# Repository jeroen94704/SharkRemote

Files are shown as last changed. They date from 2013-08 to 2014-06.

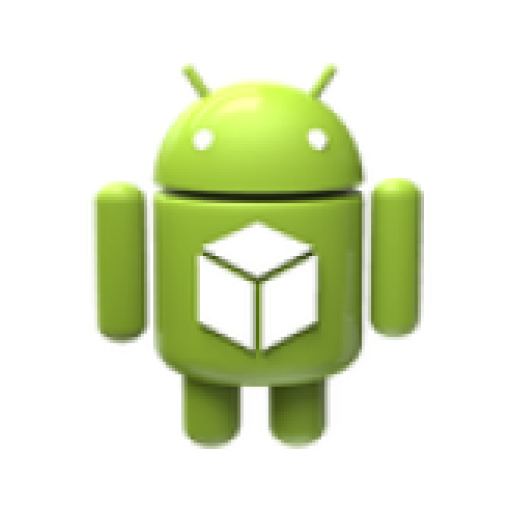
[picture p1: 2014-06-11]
AndroidApp/BruceControl/src/main/ic_launcher-web.png

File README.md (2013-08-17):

SharkRemote
===========

The goal of this project is to convert an AirSwimmer (http://www.airswimmers.com) helium balloon fish into to be controllable over a network. This is done by replacing the analog wireless control module with a n RFM12B wireless module controlled by an Atmega328 microcontroller. A base station in the form of a Nanode networked Arduino clone acts as a gateway between the RFM12B connection and the network. It provides a REST-like interface which can be used to control the AirSwimmer. 

RF12_Server
-----------

Some stuff about the server, such as the wireless protocol being used

RF12_Client
-----------

Something about the client, such as the design

REST interface
--------------

Something about the REST interface etc.

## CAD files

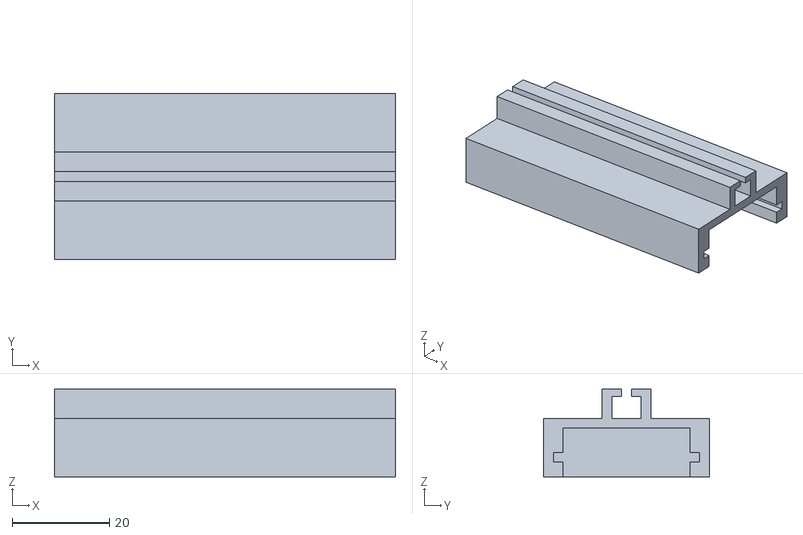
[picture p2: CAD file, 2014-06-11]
OpenScadFiles/PCB holder.stl
70.0 x 34.0 x 18.0

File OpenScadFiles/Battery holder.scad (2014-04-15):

union() {
	difference() {
		difference() {	
			translate([0,0,9])
				cube([35, 11, 6], center=true);
			translate([-1,0,8])
				cube([74, 7, 5], center=true);
		}
		translate([-1,0,10])
			cube([74, 2, 5], center=true);	
	}
	difference() {
		difference() {
			cube([35,23,12], center=true);
			translate([2, 0, -2])
			   cube([70,16,12], center=true);
		}
		translate([2, 0, 0])
		   cube([70,19,8], center=true);	
	}
}

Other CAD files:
OpenScadFiles/PCB holder.scad

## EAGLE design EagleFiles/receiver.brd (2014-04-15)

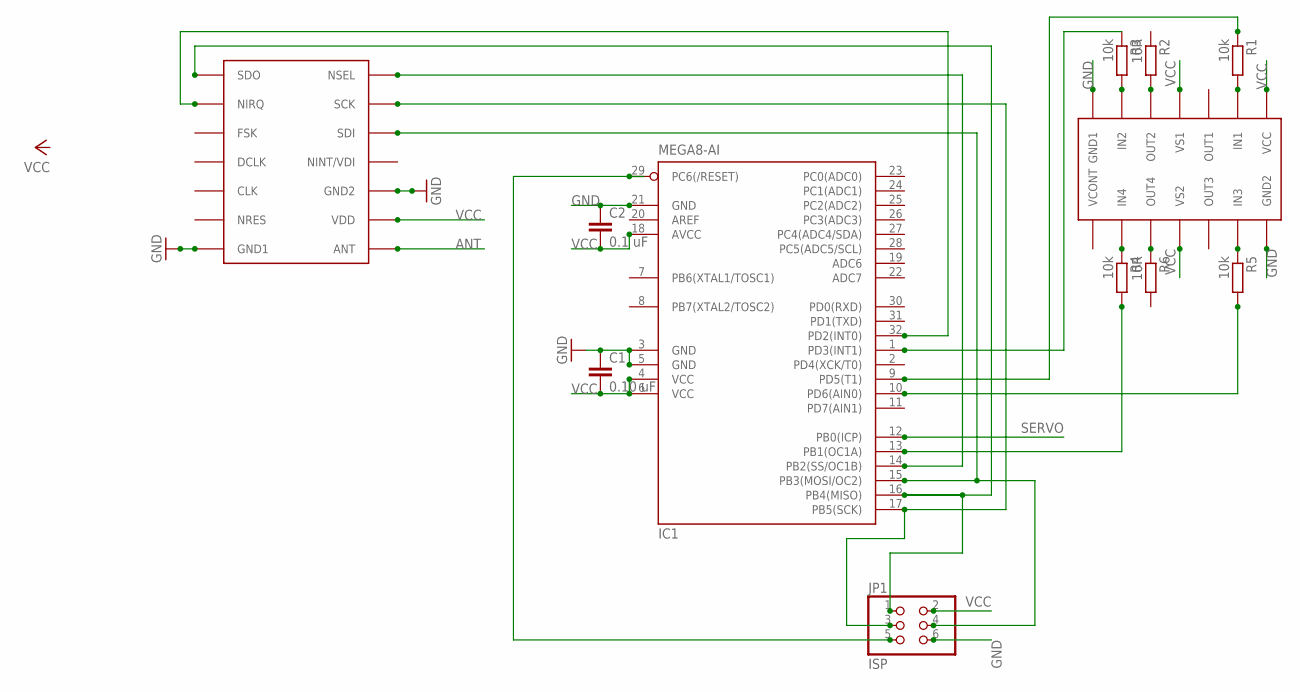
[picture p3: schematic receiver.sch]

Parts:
C1: 0.10 uF; C0805
C2: 0.1 uF; C0805
IC1: MEGA8-AI; TQFP32-08
JP1: ISP; 2X03
LB1836M: LB1836M; MFP-14
R1, R3, R4, R5: 10k; R2012
R2, R6: 10R; R2012
RFM12B: RFM12B

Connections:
ANT: RFM12B.ANT
GND: C1.1, C2.1, IC1.3 (GND), IC1.5 (GND), IC1.21 (GND), JP1.6, LB1836M.GN2 (GND2), LB1836M.GND1, RFM12B.GND1, RFM12B.GND2
unnamed: IC1.16 (PB4(MISO)), JP1.1, RFM12B.SDO
unnamed: IC1.15 (PB3(MOSI/OC2)), JP1.4, RFM12B.SDI
unnamed: IC1.17 (PB5(SCK)), JP1.3, RFM12B.SCK
unnamed: IC1.14 (PB2(SS/OC1B)), RFM12B.NSEL
unnamed: IC1.32 (PD2(INT0)), RFM12B.NIRQ
unnamed: LB1836M.IN1, R1.2
unnamed: IC1.9 (PD5(T1)), R1.1
unnamed: LB1836M.IN2, R3.2
unnamed: LB1836M.IN4, R4.1
unnamed: LB1836M.IN3, R5.1
unnamed: IC1.1 (PD3(INT1)), R3.1
unnamed: IC1.13 (PB1(OC1A)), R4.2
unnamed: IC1.10 (PD6(AIN0)), R5.2
unnamed: LB1836M.OUT2, R2.2
unnamed: LB1836M.OUT4, R6.1
unnamed: IC1.29 (PC6(/RESET)), JP1.5
SERVO: IC1.12 (PB0(ICP))
VCC: C1.2, C2.2, IC1.4 (VCC), IC1.6 (VCC), IC1.18 (AVCC), JP1.2, LB1836M.VCC, LB1836M.VS1, LB1836M.VS2, RFM12B.VDD

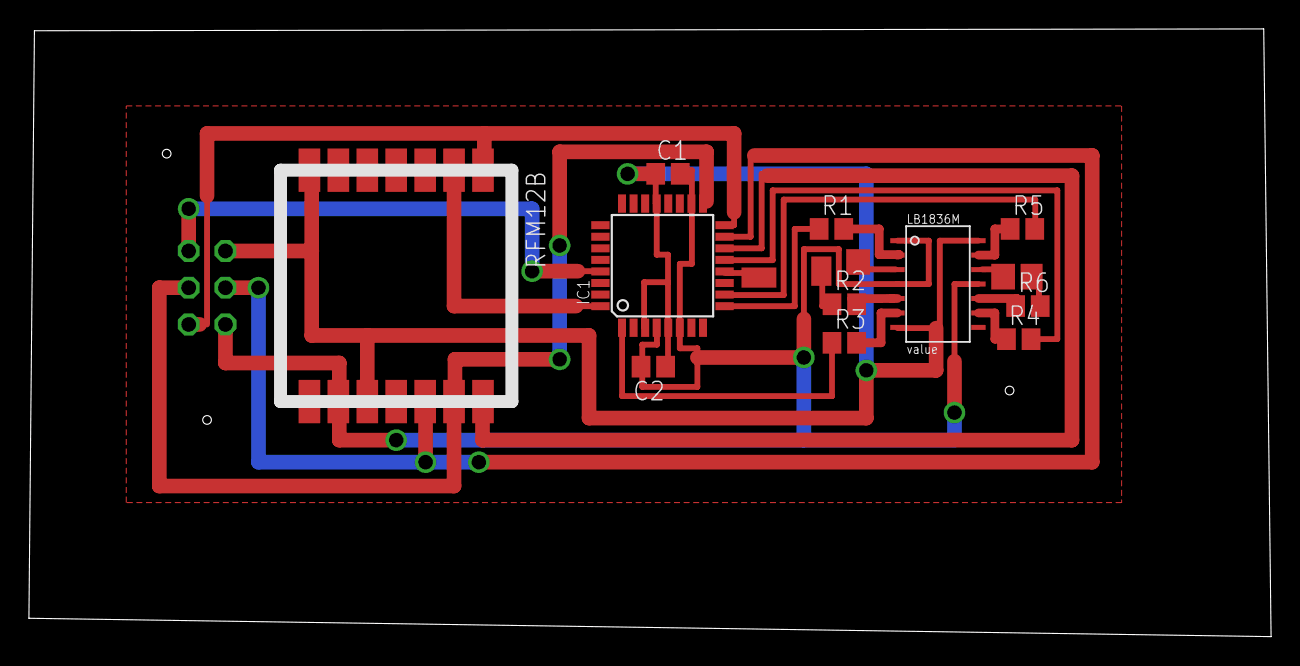
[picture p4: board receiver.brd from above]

Board: 2 copper layers, 85.9 x 42.0 mm, 12 parts (1 on the bottom side), 18 nets.

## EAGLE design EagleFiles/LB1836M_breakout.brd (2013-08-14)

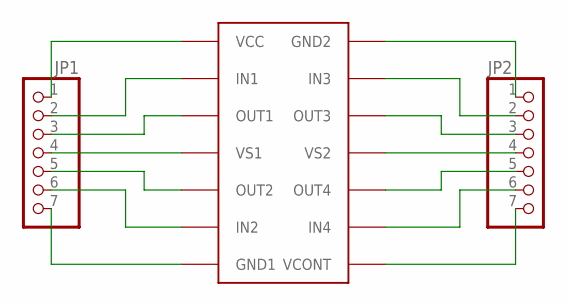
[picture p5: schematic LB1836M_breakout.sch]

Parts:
JP1, JP2: PINHD-1X7; 1X07
LB1836M: LB1836M; MFP-14

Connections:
unnamed: JP2.1, LB1836M.GN2 (GND2)
unnamed: JP2.2, LB1836M.IN3
unnamed: JP2.3, LB1836M.OUT3
unnamed: JP2.4, LB1836M.VS2
unnamed: JP2.5, LB1836M.OUT4
unnamed: JP2.6, LB1836M.IN4
unnamed: JP2.7, LB1836M.VCONT
unnamed: JP1.1, LB1836M.VCC
unnamed: JP1.2, LB1836M.IN1
unnamed: JP1.3, LB1836M.OUT1
unnamed: JP1.4, LB1836M.VS1
unnamed: JP1.5, LB1836M.OUT2
unnamed: JP1.6, LB1836M.IN2
unnamed: JP1.7, LB1836M.GND1

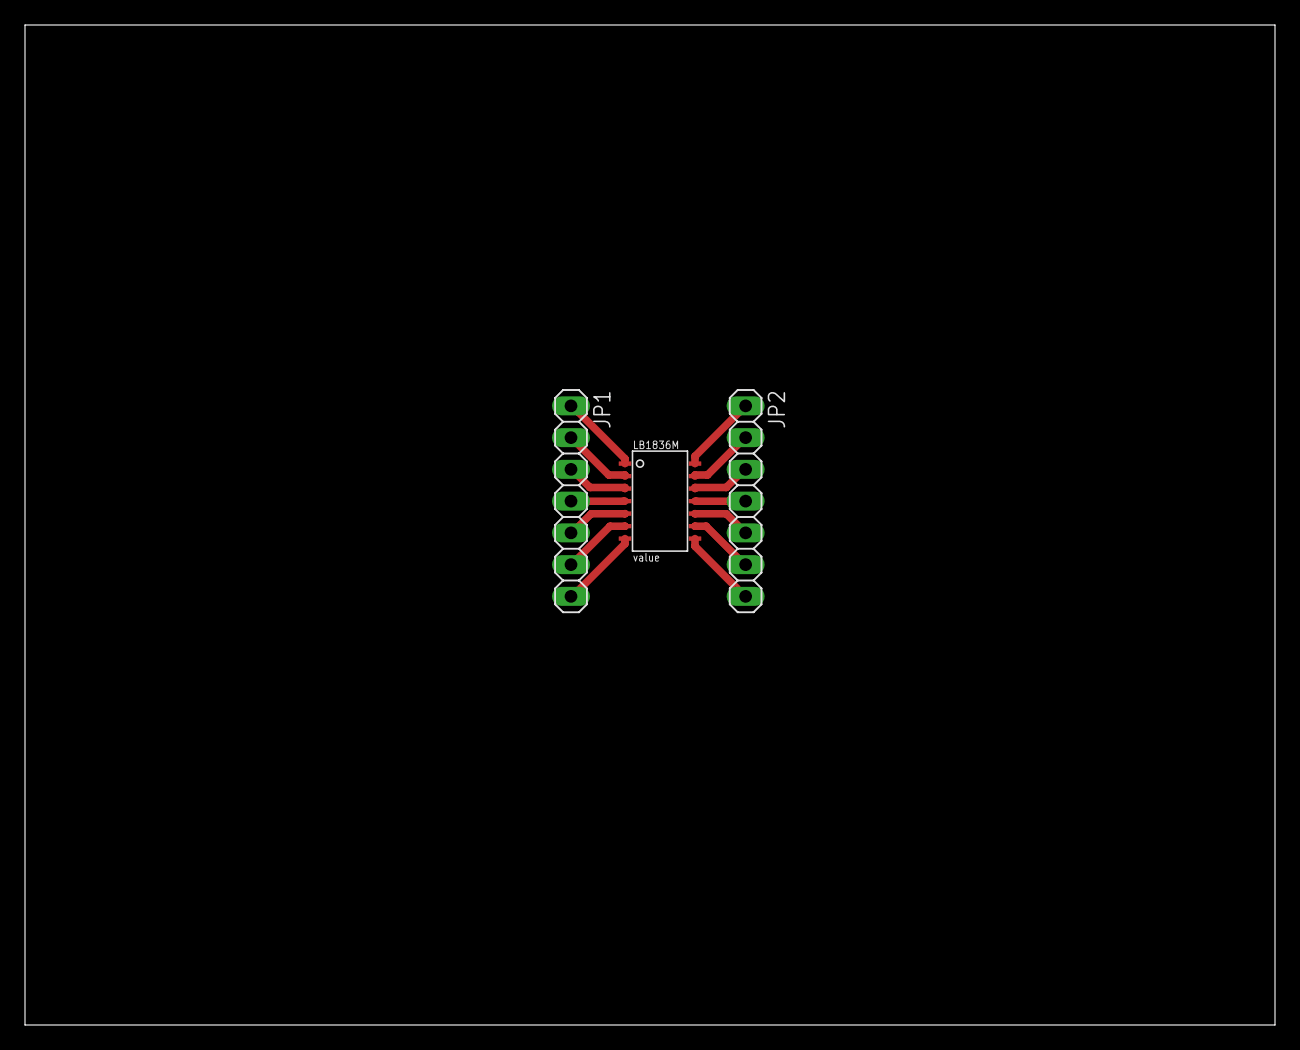
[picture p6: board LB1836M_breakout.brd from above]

Board: 2 copper layers, 100.0 x 80.0 mm, 3 parts (0 on the bottom side), 14 nets.

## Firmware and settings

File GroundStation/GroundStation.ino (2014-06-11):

#include <EtherCard.h>
#include <JeeLib.h>

#define DEBUG 1 // set to 1 to display free RAM on web page
#define SERIAL 1 // set to 1 to show incoming requests on serial port

// Motor pins
#define m11 3
#define m12 5
#define m21 6
#define m22 9
#define servoPin 8

#define PWMval  80

#define propMinVal 15
#define propMaxVal 100

#define servoMinVal 30
#define servoMaxVal 180

// Pin ID's
#define unknown 0
#define lprop 1
#define rprop 2
#define servo 3

// buffer for an outgoing data packet
static byte outBuf[RF12_MAXDATA], outDest;
static char outCount = -1;

char payload[10];

// supertweet.net username:password in base64
#define KEY   "U2hhcmtUd2VldDE6a2Fhc2thYXM="
#define API_URL "/1.1/statuses/update.json"

// ethernet interface mac address, must be unique on the LAN
byte mymac[] = { 0x74,0x69,0x69,0x2D,0x30,0x3 };
byte staticip[] = {192, 168, 0, 3 };

static BufferFiller bfill; // used as cursor while filling the buffer
byte Ethernet::buffer[500];
uint8_t runTime;

char okHeader[] PROGMEM =
    "HTTP/1.0 200 OK\r\n"
    "Content-Type: text/html\r\n";

char badRequest[] PROGMEM =
    "HTTP/1.0 400 Bad Request\r\n"
    "Content-Type: text/html\r\n"
    "\r\n"
    "<h1>400 Bad Request</h1>";

void setup()
{
  Serial.begin(57600); 
  Serial.print("Initializing RF12 ... ");
  rf12_initialize(1, RF12_433MHZ, 33);
  Serial.println("done");

  Serial.print("\nInitializing ethernet ... ");

  if (ether.begin(sizeof Ethernet::buffer, mymac) == 0) 
    Serial.println( "Failed to access Ethernet controller");
  if (!ether.dhcpSetup())
    Serial.println("DHCP failed");

  Serial.println("done");

  ether.printIp("IP:  ", ether.myip);
}

void sendAnalogValue(int portNum, byte value)
{
  sprintf(payload, "WD%02d%03d\0", portNum, value);
  Serial.print("Sending command ");
  Serial.print(payload);
  Serial.println(" over wireless");
  rf12_sendStart(0, payload, sizeof payload);
  rf12_sendWait(0);
  while (!rf12_canSend()) rf12_recvDone();
}

// Assuming a url of the form /pins/<pinid>?... , Starting at the provided offset, extract the pin id
int getPinId(const char* data, byte offset) {
    int pin = -1;
    int numChars = 0;

    char* untilPtr = strchr(data + offset, '?');

    if (untilPtr != NULL)
    {
      numChars = untilPtr - (data + offset);
    }
    else
    {
      untilPtr = strchr(data + offset, ' ');
      numChars = untilPtr - (data + offset);
    }

    char temp[6];
    if(numChars < 6)
    {
      strncpy(temp, data + offset, numChars);
      temp[numChars] = '\0';
    #ifdef DEBUG
    Serial.print("pindid = ");
    Serial.println(temp);
    #endif
      if(strcmp(temp, "lprop") == 0)
        return lprop;
      else if(strcmp(temp, "rprop") == 0)
        return rprop;
      else if(strcmp(temp, "servo") == 0)
        return servo;
    }

    return unknown;
}

int getIntArg(const char* data, const char* key, int value =-1) {
    char temp[10];
    if (ether.findKeyVal(data, temp, sizeof(temp), key) > 0)
        value = atoi(temp);
    return value;
}

void processPropVal(int value, int pin1, int pin2)
{
  int thePin;
  
  sendAnalogValue(pin1, 0);
  sendAnalogValue(pin2, 0);

  if(value == 0) 
  {            
    return;
  }
  
  if(value > 0)
  {
    thePin = pin1;
  } 
  else
  {
    value *= -1;
    thePin = pin2;
  }
  
  // Clip to 0-100
  value = min(value, 100);
  value = max(value, 0);
  
  // Remap value from 1-100 to 15-100 (which is the useful range for the props)
  value = map(value, 1, 100, propMinVal, propMaxVal);
  sendAnalogValue(thePin, value); 
}

void putRequest(const char* data, BufferFiller& buf)
{
  // Check if "pins" is followed by a '/', to ensure proper formatting
  if (data[11] == '/')
  {
    #ifdef DEBUG
    Serial.println("Found a '/' where expected");
    #endif

    // Get the pin number from the request
    int pinId = getPinId(data, 12);
    int thePin;
    char temp[20];
    
    if(pinId != unknown)
    {
      #ifdef DEBUG
      Serial.println("Processing put value request");
      #endif
      
      if (ether.findKeyVal(data+18, temp, sizeof(temp), "value") > 0)
      {
        int value = getIntArg(data+18, "value");
        #ifdef DEBUG
        Serial.print("Found value ");
        Serial.println(value);
        #endif
        
        switch(pinId) {
          case lprop :
            processPropVal(value, m11, m12);
          break;
          case rprop :
            processPropVal(value, m21, m22);
          break;
          case servo : 
            // Clip to 0-90
            value = min(value, 100);
            value = max(value, 0);
          
            sendAnalogValue(servoPin, map(value, 0, 100, servoMinVal, servoMaxVal));
          break;
          default:
            #ifdef DEBUG
            Serial.println("Unrecognized PUT request!");
            #endif
            bfill.emit_p(PSTR("$F"), badRequest);
            return;
          break;
        }
        
        bfill.emit_p(PSTR("$F\r\n <h1>200 OK</h1>"), okHeader);
      }
      else
      {
        #ifdef DEBUG
        Serial.println("Unrecognized PUT request!");
        #endif
        bfill.emit_p(PSTR("$F"), badRequest);
      }
    }
  }
}

// To test, use :  curl -i -H "Accept: application/json" -X GET http://192.168.0.110/1/pins/servo?value=180

void loop()
{    
    // RFM12 loop runner, don't report acks
    rf12_recvDone();

    word len = ether.packetReceive();
    word pos = ether.packetLoop(len);

    // check if valid tcp data is received
    if (pos)
    {
        bfill = ether.tcpOffset();
        char* data = (char *) Ethernet::buffer + pos;
#if SERIAL
        Serial.println(data);
#endif
        #ifdef DEBUG
        Serial.println("Received tcp data!");
        #endif
        // receive buf hasn't been clobbered by reply yet
        if (strncmp("GET /1/pins/", data, 12) == 0)
        {
          putRequest(data, bfill);
        }
        else
        {
          bfill.emit_p(PSTR("$F"), badRequest);
        }
        ether.httpServerReply(bfill.position()); // send response data
    }   
}

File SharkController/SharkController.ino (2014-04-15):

#include <JeeLib.h>
#include "SoftwareServo.h"
 
//#define RXCOMMANDS

// Servo stuff
SoftwareServo servo;
const int servoPin = 8;

// Motor pins
const int m11 = 3;
const int m12 = 5;
const int m21 = 6;
const int m22 = 9;

int PWMval = 64;
int desiredServoPos = 90;
float currentServoPos = desiredServoPos;

int vccCheckCount = 0;
int nodeID = 1;

long readVcc() 
{
  long result;
  // Read 1.1V reference against AVcc
  ADMUX = _BV(REFS0) | _BV(MUX3) | _BV(MUX2) | _BV(MUX1);
  delay(2); // Wait for Vref to settle
  ADCSRA |= _BV(ADSC); // Convert
  while (bit_is_set(ADCSRA,ADSC));
  result = ADCL;
  result |= ADCH<<8;
  result = 1126400L / result; // Back-calculate AVcc in mV
  return result;
}

// the setup routine runs once when you press reset:
void setup() 
{    
#ifdef RXCOMMANDS
  Serial.begin(57600); 
  Serial.print("Initializing RF12 ... ");
#endif
  rf12_initialize(1, RF12_433MHZ, 33);
#ifdef RXCOMMANDS
  Serial.println("done");  
#endif

  servo.attach(servoPin);
}

boolean parsePayload(volatile uint8_t* data, int len)
{
  if(strncmp((const char *)data, "WD", 2) == 0)   // Handle Write command. Only accept digital pins
  {
    char pinID[3];
    strncpy(pinID, (const char*)data+2, 2);      
    pinID[2] = '\0';

    char value[4];
    strncpy(value, (const char*)data+4, 3);      
    value[3] = '\0';

    int pinNr = atoi(pinID);
    switch(pinNr)
    {
    // Process writes to the motor pins and servo pin
    case m11:
    case m12:
    case m21:
    case m22:
      analogWrite(pinNr, atoi(value));
      break;
    case servoPin:
      desiredServoPos = atoi(value);
      break;
    }
#ifdef RXCOMMANDS
    Serial.print("Write, pin = ");
    Serial.print(pinID);
    Serial.print(", value = ");
    Serial.print(value);
    Serial.println(".");
    Serial.print("Supply voltage: ");
    Serial.print(readVcc());
    Serial.println("[mV]");
#endif
  }
  else if(strncmp((const char *)data, "MD", 1) == 0) // Handle Mode command. Only accept digital pins
  {
    // Extract the numeric part of the pinID
    char pinID[3];
    strncpy(pinID, (const char*)data+2, 2);      
    pinID[2] = '\0';
    int pinNr = atoi(pinID);

    char value[4];
    strncpy(value, (const char*)data+4, 3);      
    value[3] = '\0';

    pinMode(pinNr, (atoi(value) == 0) ? INPUT : OUTPUT);

#ifdef RXCOMMANDS
    Serial.print("Mode. pin = "); 
    Serial.print(pinID);
    Serial.print(", value = ");
    Serial.print(value);
    Serial.println(".");
#endif

  }
  else
  {
#ifdef RXCOMMANDS    
    Serial.println("couldn't parse incoming message");
#endif    
  }
}

void processIncoming()
{
  if (rf12_recvDone() && rf12_crc == 0) 
  {
    parsePayload(rf12_data, rf12_len);
  }
}

// the loop routine runs over and over again forever:
void loop()
{
  // Check if the voltage is still sufficient
  bool doProcessing = true;
  if(vccCheckCount++ > 10000)
  {
    doProcessing = readVcc() > 3000;
    vccCheckCount = 0;
  }

  if(doProcessing)
  {
    processIncoming();
  
    servo.write(currentServoPos);
    
    if(currentServoPos > desiredServoPos)
    {
      currentServoPos-=0.04;
    }
    
    if(currentServoPos < desiredServoPos)
    {
      currentServoPos+=0.04;
    }
  
    SoftwareServo::refresh(); 
  }
  else
  {
    // Switch everything off when voltage drops too low
    analogWrite(m11, 0);
    analogWrite(m12, 0);
    analogWrite(m21, 0);
    analogWrite(m22, 0);
    
    servo.detach();
  }
}

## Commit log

2013-04-01 Now controlling the tail fin over wireless
    [LB1836M_breakout.sch, receiver.brd, receiver.sch]
2013-04-21 Added eagle files for LB1836M breakout board and unfinished receiver
    [LB1836M_breakout.brd, receiver.brd, receiver.sch]
2013-05-14 Added test code for wireless comms
2013-08-14 Further development of the software
    [LB1836M_breakout.brd, LB1836M_breakout.sch, receiver.brd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]
2013-08-17 Working version of the REST-like API in the groundcontroller
2013-08-18 All REST commands now functional and processed correctly. Both on-board controller and ground station software now essentially feature complete
    [GroundStation.ino, SharkController.ino]
2014-02-25 Further development of the schematic and board
    Schematic finalized, added a pinheader for programming and corrected
    wiring errors. Board largely designed, including pads to solder the
    motor and servo wires to.
    [receiver.brd, receiver.sch]
2014-04-15 Added openscad models
    [Battery holder.scad, PCB holder.scad]
2014-04-15 Further development of software and board
    * Removed twitter publishing of ip address
    * Added on-board voltage monitoring
    * Small changes to receiver board.
2014-04-15 Small changes to board
    [receiver.brd]
2014-06-11 Added android control app
    - The android controil app is provided as an Android Studio project
    - Switched to a static IP for the ground station, at least for now.
    - Modified the PCB holder stl model
    [PCB holder.stl]
